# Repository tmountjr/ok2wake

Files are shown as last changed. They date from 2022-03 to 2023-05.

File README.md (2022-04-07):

# Intro
This is a repo with (almost) everything necessary to build an "OK to Wake" lamp - the gist is, when the lamp is a certain color, the kiddo knows to stay in bed; when it changes, it's okay to get out of bed.

# Components
There are three components to this project: the physical lamp, physical components that light up the lamp, and the software running on the lamp.

## The Physical Lamp
In some ways this was the easiest part of the project. There's an STL file included that in two pieces - the shade and the base. The base has a hole along the bottom to thread in a USB cable and a spot to rest the electronics; the shade fits into a cutout groove on the base.

Additionally, a PDF of the circuit is also included; it 

## The Electronic Components
The circuit uses an ESP8266, two RGB LEDs plus 220ohm resistors, and a switch to cut power to the LEDs regardless of what the software says to do. The base of the lamp fits two mini breadboards.

### BOM
* 1x NodeMCU ESP8266 dev board
* 2x RGB LEDs (common cathode)
* 6x 220ohm resistors
* 1x switch (this layout uses a SPDT switch but any mechanical non-momentary switch should work)

## The Software

The firmware on the ESP8266 comes in two parts: the actual system control, and a web interface to provide visibility and allow for changes. The firmware is reasonably straightforward Arduino-compatible C++; the web interface is a Vue 3 single-page app (SPA) built in the `/webserver` directory, which then compiles to the `/data` directory (which can be built and then uploaded to the ESP8266 flash storage) where it's served by the MCU.

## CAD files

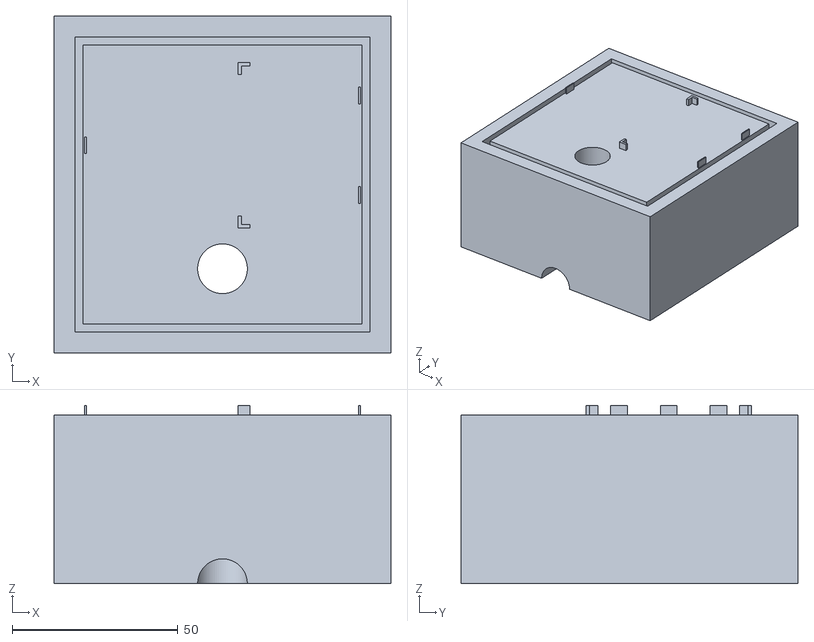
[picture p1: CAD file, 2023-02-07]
Base.stl
101.6 x 101.6 x 53.8

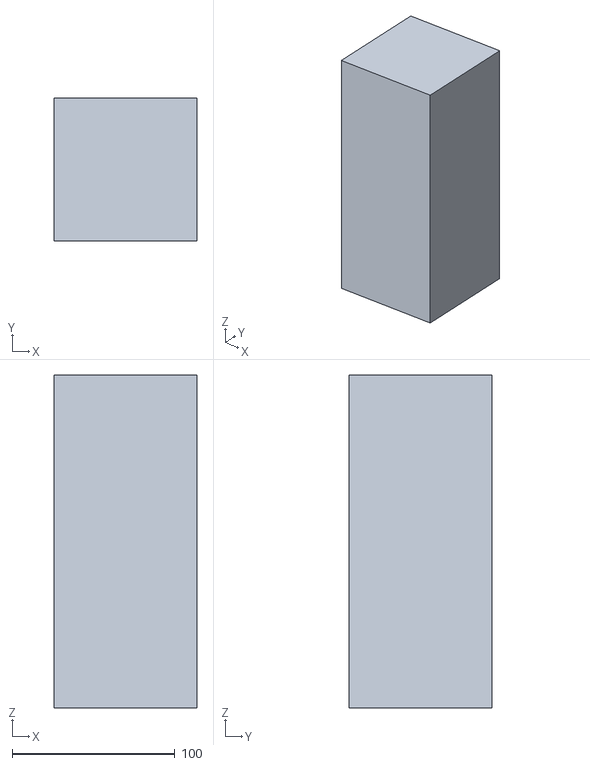
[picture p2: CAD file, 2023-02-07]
Shade.stl
87.7 x 87.7 x 204.4

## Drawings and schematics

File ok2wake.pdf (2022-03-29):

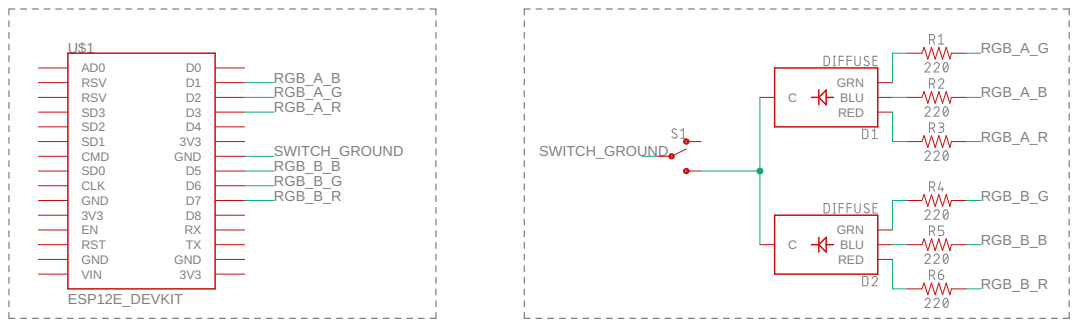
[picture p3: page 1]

Released under the Creative Commons Attribution Share-Alike 4.0 License

https://creativecommons.org/licenses/by-sa/4.0/

3/29/22 16:00 /Users/tmountjr/Documents/EAGLE/projects/ok2wake/ok2wake.sch (Sheet: 1/1)

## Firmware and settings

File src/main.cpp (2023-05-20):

#include <Arduino.h>
#include <ArduinoOTA.h>
#include <ESP8266WiFi.h>

// Include config.
#include "secrets.h"

// Set up global variables.
#include "globals.h"

// Include LED information
#include "led.h"

// Include web server functionality.
#include "WebServer.h"

#ifndef WIFI_PASSWORD
#define WIFI_PASSWORD "Please define WIFI_PASSWORD in src/secrets.h"
#endif

#ifndef WIFI_SSID
#define WIFI_SSID "Please define WIFI_SSID in src/secrets.h"
#endif

void setup()
{
  Serial.begin(115200);

  setUpLed();

  Serial.print("\nStarting wifi");
  WiFi.hostname("ok2wake");
  WiFi.begin(WIFI_SSID, WIFI_PASSWORD);
  while (WiFi.status() != WL_CONNECTED)
  {
    Serial.print(".");
    delay(1000);
  }
  Serial.println(" Connected!");
  Serial.print("IP Address: ");
  Serial.println(WiFi.localIP());
  Serial.println("");

  // Set up filesystem.
  LittleFS.begin();

  // Read settings.
  readSettings();

  // Set up WiFi server
  wifiServerSetup();

  ArduinoOTA.begin();

  timeClient.begin();

  // Retrieve the settings from flash and use the timezone name that was last saved.
  // Default to "America/New_York" (set above) if there's a problem.
  File settingsFile = LittleFS.open("settings.json", "r");
  if (!settingsFile)
  {
    Serial.println("Unable to open 'settings.json' from flash. Using defaults.");
  }
  else
  {
    StaticJsonDocument<512> settingsDoc;
    DeserializationError e = deserializeJson(settingsDoc, settingsFile);
    if (e)
    {
      Serial.println("Unable to deserialize 'settings.json' from flash. Using defaults.");
      Serial.println(e.c_str());
    }
    else
    {
      tz_name = settingsDoc["tz_name"].as<String>();
    }
  }
  updateTimeClient();

  // A sane set of defaults has been provided as part of the firmware in events.json.
  File defaultEventList = LittleFS.open(eventsPath, "r");
  StaticJsonDocument<512> doc;
  DeserializationError e = deserializeJson(doc, defaultEventList);
  if (e)
  {
    Serial.println("Failed to read user config.");
    // Put in a placeholder that keeps the thing turned off.
    LEDEvent *event = new LEDEvent(0, 0, LEDEvent::LED_STATE_OFF);
    ll.add(event);
  }
  else
  {
    for (JsonObject item : doc["events"].as<JsonArray>())
    {
      int hour = item["hour"];
      int minute = item["minute"];
      int state = item["state"];
      LEDEvent *event = new LEDEvent(hour, minute, state);
      ll.add(event);
    }
  }
  findCurrent(ll);
  targetLedStatus = current->data->state;

  #ifdef IP_TRACKER
  char url[128];
  strcpy(url, IP_TRACKER);
  strcat(url, WiFi.localIP().toString().c_str());
  Serial.printf("\n Pinging url %s...\n", url);
  HTTPClient httpTracker;
  if (httpTracker.begin(client, url))
  {
    int httpCode = httpTracker.GET();
    Serial.printf("Pinged IP tracker. Status Code = %i\n", httpCode);
  }
  #endif
}

void loop()
{
  if (nextUp->data->hour == timeClient.getHours() && nextUp->data->minute == timeClient.getMinutes())
  {
    current = current->next;
    nextUp = current->next;
    targetLedStatus = current->data->state;
  }

  switch (targetLedStatus)
  {
  case LEDEvent::LED_STATE_WAKE:
    wake();
    break;
  case LEDEvent::LED_STATE_SLEEP:
    sleep();
    break;
  case LEDEvent::LED_STATE_NIGHT_LIGHT:
    night_light();
    break;
  case LEDEvent::LED_STATE_CUSTOM:
    custom();
    break;
  case LEDEvent::LED_STATE_OFF:
  default:
    off();
    break;
  }

  ArduinoOTA.handle();
  server.handleClient();
}

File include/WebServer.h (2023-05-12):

/**
 * The web server functionality has been abstracted here as much as possible.
 * Routes are defined at the end of the file once all the handlers have been defined.
 * All other global variables should come from globals.h.
 */

#include "globals.h"
#include <ArduinoJson.h>
#include <LittleFS.h>

void corsResponse()
{
  server.sendHeader("Access-Control-Allow-Origin", "*");
  server.send(204, "text/plain", "");
  
}

void notFoundResponse()
{
  server.send(404, "text/plain", "Not Found");
}

void invalidRequestResponse(int status = 400, String msg = "Bad Request")
{
  server.send(status, "text/plain", msg);
}

void getHomeResponse()
{
  HTTPMethod method = server.method();
  if (!(method == HTTP_GET || method == HTTP_HEAD))
    invalidRequestResponse(405, "Method Not Allowed");
  else
  {
    File index = LittleFS.open("index.html", "r");
    String indexStr;
    if (index.available())
    {
      indexStr = index.readString();
      server.send(200, "text/html", indexStr);
    }
    else
      server.send(503, "text/plain", "Service Unavailable");
  }
}

void setTimeZoneResponse()
{
  HTTPMethod method = server.method();
  if (!(method == HTTP_POST || method == HTTP_OPTIONS))
    invalidRequestResponse(405, "Method Not Allowed");

  if (method == HTTP_OPTIONS)
    corsResponse();
  else
  {
    StaticJsonDocument<512> inputDoc;
    deserializeJson(inputDoc, server.arg("plain"));
    tz_name = inputDoc["tz_name"].as<String>();
    updateTimeClient();
    StaticJsonDocument<96> jsonObject;
    jsonObject["t"] = timeClient.getEpochTime();
    jsonObject["s"] = targetLedStatus;
    jsonObject["o"] = tz_offset;
    jsonObject["tz"] = tz_name;
    String jsonObjectString;
    serializeJson(jsonObject, jsonObjectString);
    server.sendHeader("Access-Control-Allow-Origin", "*");
    server.send(200, "application/json", jsonObjectString);

    // Write the new value back to flash memory.
    writeSettings();
  }
}

void setEventsResponse()
{
  HTTPMethod method = server.method();
  if (!(method == HTTP_POST || method == HTTP_OPTIONS))
    invalidRequestResponse(405, "Method Not Allowed");

  if (method == HTTP_OPTIONS)
    corsResponse();
  else
  {
    StaticJsonDocument<512> inputDoc;
    deserializeJson(inputDoc, server.arg("plain"));
    LinkedList<LEDEvent> newLL;
    for (JsonObject item : inputDoc.as<JsonArray>())
    {
      int hour = item["hour"];
      int minute = item["minute"];
      int state = item["state"];
      LEDEvent *e = new LEDEvent(hour, minute, state);
      newLL.add(e);
    }
    ll = newLL;
    findCurrent(ll);
    
    LittleFS.remove(eventsPath);
    File file = LittleFS.open(eventsPath, "w");
    if (!file)
    {
      Serial.println("Error creating user config file.");
      server.send(500, "text/plain", "Cannot create user config file; the config has been saved in temporary flash storage.");
    }
    bool seenHead = false;
    Node<LEDEvent> *c = ll.head;
    StaticJsonDocument<512> outputDoc;
    JsonArray events = outputDoc.createNestedArray("events");
    while (!seenHead) {
      JsonObject o = events.createNestedObject();
      o["hour"] = c->data->hour;
      o["minute"] = c->data->minute;
      o["state"] = c->data->state;
      c = c->next;
      if (c == ll.head)
        seenHead = true;
    }
    if (serializeJson(outputDoc, file) == 0)
    {
      Serial.println("Error writing new user config file.");
      server.send(500, "text/plain", "Error saving new config file; the config has been saved in temporary flash storage.");
    }

    server.send(200, "text/plain");
  }
}

void getEventsResponse()
{
  HTTPMethod method = server.method();
  if (!(method == HTTP_GET || method == HTTP_HEAD || method == HTTP_OPTIONS))
    invalidRequestResponse(405, "Method Not Allowed");

  if (method == HTTP_HEAD)
    server.send(200, "application/json", "");
  else if (method == HTTP_OPTIONS)
    corsResponse();
  else
  {
    bool seenCurrent = false;
    Node<LEDEvent> *c = current;
    StaticJsonDocument<512> doc;
    JsonArray events = doc.createNestedArray("events");
    while (!seenCurrent) {
      JsonObject o = events.createNestedObject();
      o["hour"] = c->data->hour;
      o["minute"] = c->data->minute;
      o["state"] = c->data->state;
      c = c->next;
      if (c == current)
        seenCurrent = true;
    }
    String jsonObjectString;
    serializeJson(doc, jsonObjectString);
    server.sendHeader("Access-Control-Allow-Origin", "*");
    server.send(200, "application/json", jsonObjectString);
  }
}

void getStatusResponse()
{
  HTTPMethod method = server.method();
  if (method == HTTP_HEAD)
    server.send(200, "application/json", "");
  else if (method == HTTP_OPTIONS)
    corsResponse();
  else if (method == HTTP_GET)
  {
    StaticJsonDocument<96> jsonObject;
    jsonObject["t"] = timeClient.getEpochTime();
    jsonObject["s"] = targetLedStatus;
    jsonObject["o"] = tz_offset;
    jsonObject["tz"] = tz_name;
    String jsonObjectString;
    serializeJson(jsonObject, jsonObjectString);
    server.sendHeader("Access-Control-Allow-Origin", "*");
    server.send(200, "application/json", jsonObjectString);
  }
  else
    invalidRequestResponse(405, "Method Not Allowed");
}

void setLedStatusResponse()
{
  HTTPMethod method = server.method();
  if (!(method == HTTP_POST || method == HTTP_PUT))
    invalidRequestResponse(405, "Method Not Allowed");
  else if (method == HTTP_OPTIONS)
    corsResponse();
  else
  {
    // Go through the input and look for "state"
    for (int i = 0; i < server.args(); i++)
    {
      if (server.argName(i) == "state")
      {
        int newState = server.arg(i).toInt();
        if (
          newState == LEDEvent::LED_STATE_OFF ||
          newState == LEDEvent::LED_STATE_SLEEP ||
          newState == LEDEvent::LED_STATE_WAKE ||
          newState == LEDEvent::LED_STATE_NIGHT_LIGHT ||
          newState == LEDEvent::LED_STATE_CUSTOM
        )
        {
          targetLedStatus = newState;
          server.send(200, "text/plain", "OK");
        }
        break;
      }
    }
    invalidRequestResponse();
  }
}

void resetResponse()
{
  HTTPMethod method = server.method();
  if (!(method == HTTP_POST || method == HTTP_PUT))
    invalidRequestResponse(405, "Method Not Allowed");
  else if (method == HTTP_OPTIONS)
    corsResponse();
  else {
    targetLedStatus = current->data->state;
    server.send(200, "text/plain", "OK");
  }
}
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

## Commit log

2022-03-29 added pdf schematic
2022-03-30 add express log server and additional classes for arduino
2022-04-03 fix type conversion error causing kernel panic
    [main.cpp]
2022-04-04 update test and target method to find current, not next
2022-04-04 somewhat major refactor
    * remove queue and replace with linkedlist
    * remove web logging functionality
    [WebServer.h, main.cpp]
2022-04-04 refactor some led functionality into their own include
2022-04-04 swap in dimmable rgb led library
    [led.h]
2022-04-07 refactor complete()
    * on individual LEDs to be a bool
    * to be a function that looks at multiple pieces of info
2022-04-07 big overhaul of web server and led handling
    web server:
    * set up proper cors handling
    * added a home page route
    * set up a vue 3 spa that compiles to...
    * ...flash storage to serve static assets
    led:
    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
2022-04-07 add led event for isCurrent()
2022-04-09 add mdns, may or may not work
    [main.cpp]
2022-04-29 set the hostname a different way, also put in code (not working) for static IP
    [main.cpp]
2023-02-07 add STL files for base and shade
    [Base.stl, Shade.stl]
2023-05-12 try to get https working...and fail.
    probably not enough memory for ssl.
    [main.cpp]
